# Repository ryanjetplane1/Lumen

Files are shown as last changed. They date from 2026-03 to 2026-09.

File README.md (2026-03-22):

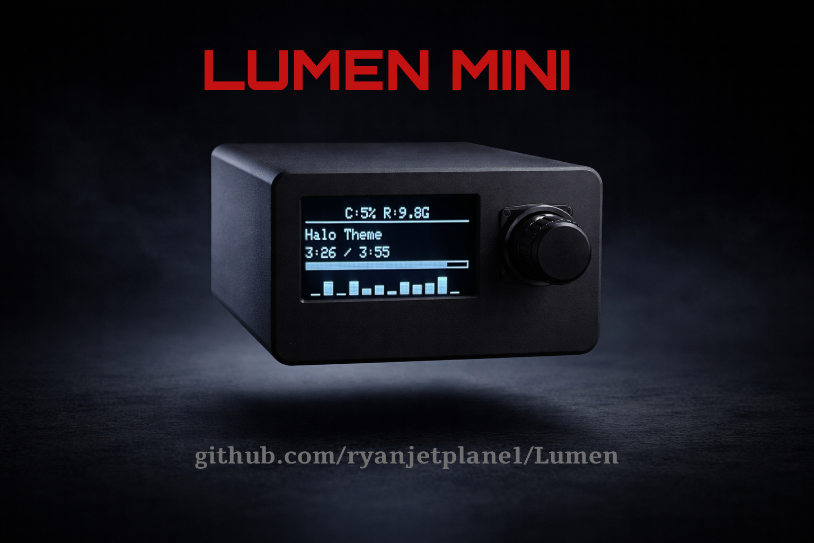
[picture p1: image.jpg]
Lumen Mini


# Lumen Mini

Lumen Mini is a pocket sized system monitor powered by USB-C that sits on your desk for extra functionality. Built on the ESP32, it houses a 1.3" OLED display showing CPU load, RAM usage, and whatever is playing. Complete with a prebuilt progress bar and a synth GUI the hardware can be reprogramed to fit your needs. When you reach for the volume, a rotary encoder handles it along with play, pause, and skip. When you turn off your PC, Lumen Mini fades to a simple clock.

---

## Features

- CPU % and RAM usage
- Current track name, progress bar, and position timer
- Synth visualizer
- Clock (12-hour)
- Volume control via rotary encoder
- Single / double / triple click for pause, next, previous track
- WiFi NTP clock fallback when PC is disconnected

---

## Hardware Required

| Part | Notes |
|---|---|
| ESP32-C3 SuperMini | Any vendor; black PCB version |
| 1.3" SH1106 OLED (128×64) | I2C, 4-pin **not** the 0.96" SSD1306 |
| Rotary encoder with pushbutton | EC11 or equivalent |
| Breadboard + jumper wires | Or solder directly |

---

## Wiring

All logic runs at **3.3V**. Do **not** use 5V — the Oled display cannot handle 5V.

### OLED Display (I2C)

| OLED Pin | ESP32-C3 SuperMini Pin |
|---|---|
| VCC | 3.3V |
| GND | GND |
| SDA | GPIO8 |
| SCL | GPIO9 |

### Rotary Encoder

| Encoder Pin | ESP32-C3 SuperMini Pin | Notes |
|---|---|---|
| VCC (+) | 3.3V | |
| GND | GND | |
| CLK (A) | **GPIO10** | Hardware interrupt pin |
| DT (B) | **GPIO2** | Hardware interrupt pin |
| SW (button) | **GPIO3** | |

---

## Software Setup

### PC Side (Python)

**Requirements:** Windows 10/11, Python 3.10+

Install dependencies:
```
pip install psutil pyserial keyboard pycaw comtypes winrt-runtime
```

Edit `gui.py` and set your COM port to whichever yours is set to:
```python
COM_PORT = 'COM3'
```

Run:
```
python gui.py
```

> The script must be running for the display to show PC stats. It will also control media keys via the encoder.

### ESP32 Side (Arduino)

**Arduino IDE board setup:**
1. In Arduino IDE, go to **File → Preferences**
2. Add to Additional Boards Manager URLs:
   `https://raw.githubusercontent.com/espressif/arduino-esp32/gh-pages/package_esp32_index.json`
3. Go to **Tools → Board → Boards Manager**, search `esp32` by Espressif and install
4. Select board: **Tools → Board → esp32 → ESP32C3 Dev Module**
5. Set **USB CDC On Boot: Enabled** (required for Serial over USB-C)

**Install libraries** via Library Manager:
- `Adafruit SH110X`
- `Adafruit GFX Library`

Edit the sketch and set your WiFi credentials:
```cpp
const char* ssid     = "your-network";
const char* password = "your-password";
```

Set your timezone offset in seconds from UTC:
```cpp
const long gmtOffset_sec = -18000;  // UTC-5 (Eastern Standard Time)
const int  daylightOffset_sec = 3600;  // 1 hour DST
```

Upload the sketch via USB-C.

---

## How It Works

```
[Windows PC]
  Python script reads:
    - CPU / RAM via psutil
    - Media info via Windows Media Transport Controls (winrt)
    - System volume via pycaw
  Sends packets over USB serial ~20x per second

[ESP32-C3 SuperMini]
  Receives packet, parses fields
  Encoder interrupts → sends CW / CCW / PAUSE / NEXT / PREV back to PC
  Python receives those and fires media/volume keyboard shortcuts
  Display renders based on current state
```

---

## Display Modes

| Condition | Display Shows |
|---|---|
| No PC connection | WiFi NTP clock + date |
| PC connected, music playing | Song name, progress bar, synth visualizer |
| PC connected, music paused | clock (12h) + Stats |
| Volume changed | Volume % overlay + bar for 1.5s |

---

## Troubleshooting

**Display shows nothing after upload**
Confirm SDA/SCL are on GPIO8/GPIO9. Confirm the display is SH1106 and not SSD1306 (different driver).

**Serial not connecting / wrong COM port**
Check Device Manager on Windows. Make sure no other program (Arduino IDE Serial Monitor, etc.) has the port open.

**Encoder feels jittery or skips**
Add a 100nF ceramic capacitor between CLK and GND, and between DT and GND, right at the encoder pins. This filters electrical noise on the interrupt lines.

**WiFi clock shows wrong time**
Adjust `gmtOffset_sec` for your timezone. EST = -18000, CST = -21600, MST = -25200, PST = -28800. If DST is active add 3600.

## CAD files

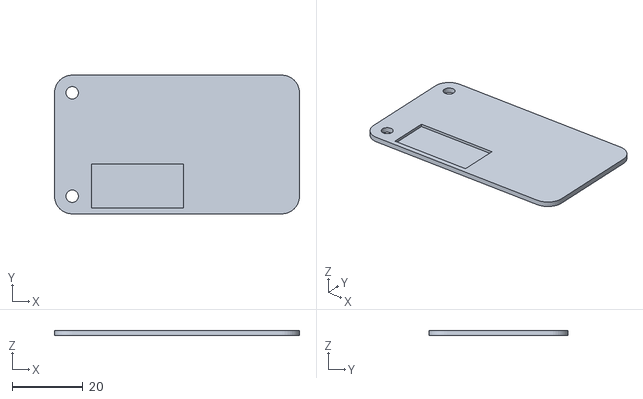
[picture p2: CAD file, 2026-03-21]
3dfiles/v4back.stl
69.2 x 39.2 x 1.50

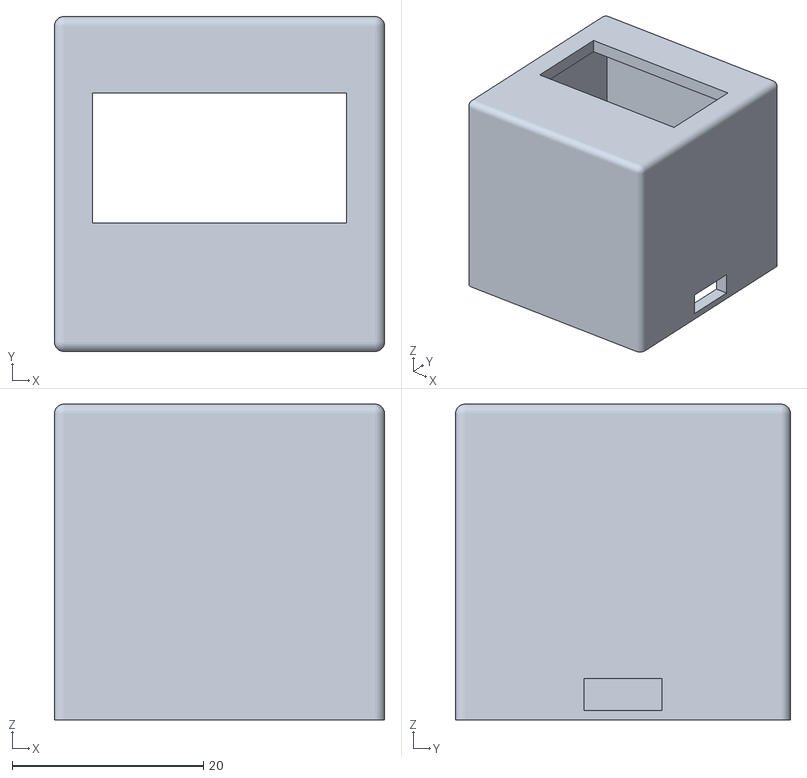
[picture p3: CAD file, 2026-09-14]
3dfiles0.96/Body5.stl
34.5 x 35.0 x 33.0

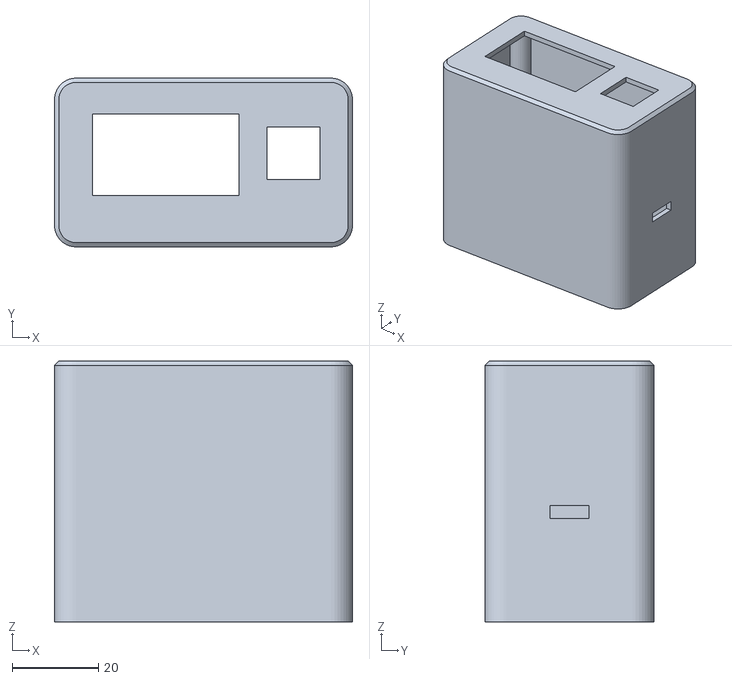
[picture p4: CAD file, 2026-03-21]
3dfiles/v5case.stl
69.2 x 39.2 x 60.6

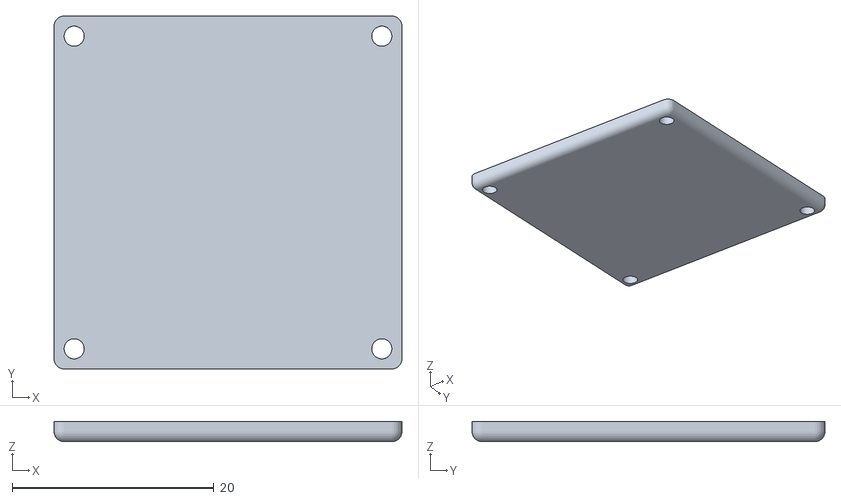
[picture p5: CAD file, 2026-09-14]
3dfiles0.96/Body6.stl
34.5 x 35.0 x 2.00

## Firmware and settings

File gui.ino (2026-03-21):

#include <WiFi.h>
#include <time.h>
#include <Wire.h>
#include <Adafruit_GFX.h>
#include <Adafruit_SH110X.h>

const char* ssid     = "timberlawn-kids";
const char* password = "11005Sugarbush";
const char* ntpServer = "pool.ntp.org";
const long  gmtOffset_sec = -18000;
const int   daylightOffset_sec = 3600;

#define SCREEN_WIDTH 128
#define SCREEN_HEIGHT 64
#define OLED_RESET -1
#define SCREEN_ADDRESS 0x3C
#define SDA_PIN 8
#define SCL_PIN 9

Adafruit_SH1106G display = Adafruit_SH1106G(SCREEN_WIDTH, SCREEN_HEIGHT, &Wire, OLED_RESET);

const int pinCLK = 10;
const int pinDT  = 2;
const int pinSW  = 3;

volatile int volumeChange = 0;
int pcVolume = 0;
unsigned long lastTickMillis   = 0;
unsigned long volDisplayTimeout = 0;
int currentPos = 0, totalDur = 0;
bool isPlaying = false, pcConnected = false;
String currentSong = "", lastSong = "";
String currentCPU = "0", currentRAM = "0", currentH = "12", currentM = "00";
int visualizerBars[12] = {0};

// ── BUTTON CLICK STATE ───────────────────────────────────────
int  clickCount       = 0;
bool btnWasPressed    = false;
unsigned long lastClickTime = 0;
const unsigned long clickTimeout = 350;  // ms window to collect clicks
const unsigned long debounce     = 40;   // ms debounce
unsigned long lastDebounceTime   = 0;
bool lastRawBtn = false;
bool stableBtn  = false;

// ── SCROLL STATE ─────────────────────────────────────────────
int  scrollOffset    = 0;
unsigned long lastScrollTime  = 0;
const int SCROLL_SPEED_MS     = 350;
const int SCROLL_PAUSE_MS     = 2000;
const int MAX_VISIBLE_CHARS   = 21;
bool scrollPausing            = false;
unsigned long scrollPauseStart = 0;
String lastScrollSong         = "";

unsigned long lastDisplayUpdate = 0;
const int DISPLAY_UPDATE_MS     = 50;

void IRAM_ATTR readEncoder() {
  static int lastCLK = -1;
  int currentCLK = digitalRead(pinCLK);
  if (currentCLK != lastCLK && currentCLK == LOW) {
    if (digitalRead(pinDT) == currentCLK) volumeChange++;
    else                                   volumeChange--;
  }
  lastCLK = currentCLK;
}

String formatTime(int totalSeconds) {
  int m = totalSeconds / 60, s = totalSeconds % 60;
  return String(m) + ":" + (s < 10 ? "0" : "") + String(s);
}

void drawCenteredText(String text, int y, int size) {
  display.setTextSize(size);
  int16_t x1, y1; uint16_t w, h;
  display.getTextBounds(text, 0, 0, &x1, &y1, &w, &h);
  display.setCursor((SCREEN_WIDTH - w) / 2, y);
  display.print(text);
}

String getValue(String data, char sep, int index) {
  int found = 0, strIndex[] = {0, -1}, maxIndex = data.length() - 1;
  for (int i = 0; i <= maxIndex && found <= index; i++) {
    if (data.charAt(i) == sep || i == maxIndex) {
      found++;
      strIndex[0] = strIndex[1] + 1;
      strIndex[1] = (i == maxIndex) ? i + 1 : i;
    }
  }
  return found > index ? data.substring(strIndex[0], strIndex[1]) : "";
}

bool barsAllZero() {
  for (int i = 0; i < 12; i++) if (visualizerBars[i] > 0) return false;
  return true;
}

void drawScrollingSong(String song, int y) {
  display.setTextSize(1);
  if (song != lastScrollSong) {
    scrollOffset     = 0;
    scrollPausing    = true;
    scrollPauseStart = millis();
    lastScrollSong   = song;
  }
  int songLen = song.length();
  if (songLen <= MAX_VISIBLE_CHARS) {
    display.setCursor(0, y);
    display.print(song);
    return;
  }
  if (scrollPausing) {
    if (millis() - scrollPauseStart >= SCROLL_PAUSE_MS) {
      scrollPausing  = false;
      lastScrollTime = millis();
    }
    display.setCursor(0, y);
    display.print(song.substring(0, MAX_VISIBLE_CHARS));
    return;
  }
  if (millis() - lastScrollTime >= SCROLL_SPEED_MS) {
    scrollOffset++;
    lastScrollTime = millis();
    if (scrollOffset >= songLen + 3) {
      scrollOffset     = 0;
      scrollPausing    = true;
      scrollPauseStart = millis();
    }
  }
  String padded = song + "   " + song;
  display.setCursor(0, y);
  display.print(padded.substring(scrollOffset, scrollOffset + MAX_VISIBLE_CHARS));
}

// ── BUTTON: debounce + multi-click detection ─────────────────
void handleButton() {
  bool rawBtn = (digitalRead(pinSW) == LOW);

  // Debounce
  if (rawBtn != lastRawBtn) lastDebounceTime = millis();
  lastRawBtn = rawBtn;
  if (millis() - lastDebounceTime < debounce) return;

  bool pressed = rawBtn;

  // Rising edge — count click
  if (pressed && !stableBtn) {
    clickCount++;
    lastClickTime = millis();
  }
  stableBtn = pressed;

  // Once the click window expires, fire the action
  if (clickCount > 0 && !pressed && (millis() - lastClickTime > clickTimeout)) {
    if      (clickCount == 1) Serial.println("PAUSE");
    else if (clickCount == 2) Serial.println("NEXT");
    else if (clickCount == 3) Serial.println("PREV");
    clickCount = 0;
  }
}

void setup() {
  Serial.begin(115200);
  Wire.begin(SDA_PIN, SCL_PIN);
  pinMode(pinCLK, INPUT_PULLUP);
  pinMode(pinDT,  INPUT_PULLUP);
  pinMode(pinSW,  INPUT_PULLUP);
  attachInterrupt(digitalPinToInterrupt(pinCLK), readEncoder, CHANGE);
  if (!display.begin(SCREEN_ADDRESS, true)) { for (;;); }
  display.clearDisplay();
  display.setTextColor(SH110X_WHITE);
  drawCenteredText("Connecting WiFi...", 25, 1);
  display.display();
  WiFi.begin(ssid, password);
  while (WiFi.status() != WL_CONNECTED) { delay(500); }
  configTime(gmtOffset_sec, daylightOffset_sec, ntpServer);
}

void loop() {
  // Encoder volume
  if (volumeChange != 0) {
    volDisplayTimeout = millis();
    if (volumeChange > 0) for (int i = 0; i < abs(volumeChange); i++) Serial.println("CW");
    else                  for (int i = 0; i < abs(volumeChange); i++) Serial.println("CCW");
    volumeChange = 0;
  }

  handleButton();

  // Serial receive
  if (Serial.available() > 0) {
    String data = Serial.readStringUntil('\n');
    if (data.indexOf('|') != -1) {
      pcConnected  = true;
      currentCPU   = getValue(data, '|', 0);
      currentRAM   = getValue(data, '|', 1);
      currentSong  = getValue(data, '|', 2);
      int incomingPos = getValue(data, '|', 3).toInt();
      totalDur     = getValue(data, '|', 4).toInt();
      String barsString = getValue(data, '|', 5);
      currentH     = getValue(data, '|', 6);
      currentM     = getValue(data, '|', 7);
      isPlaying    = (getValue(data, '|', 8).toInt() == 1);
      pcVolume     = getValue(data, '|', 9).toInt();

      if (currentSong != lastSong || abs(incomingPos - currentPos) > 5) {
        currentPos = incomingPos;
        lastSong   = currentSong;
      }
      for (int i = 0; i < 12; i++)
        visualizerBars[i] = getValue(barsString, ',', i).toInt();
    }
  }

  if (isPlaying && (millis() - lastTickMillis >= 1000)) {
    lastTickMillis = millis();
    if (currentPos < totalDur) currentPos++;
  }

  if (millis() - lastDisplayUpdate < DISPLAY_UPDATE_MS) return;
  lastDisplayUpdate = millis();

  display.clearDisplay();
  display.setTextColor(SH110X_WHITE);
  struct tm timeinfo;
  bool timeValid = getLocalTime(&timeinfo);

  if (millis() - volDisplayTimeout < 1500) {
    drawCenteredText("VOLUME", 10, 1);
    drawCenteredText(String(pcVolume) + "%", 25, 3);
    display.drawRect(10, 52, 108, 8, SH110X_WHITE);
    int volBar = map(pcVolume, 0, 100, 0, 104);
    display.fillRect(12, 54, volBar, 4, SH110X_WHITE);
  }
  else if (!pcConnected) {
    if (timeValid) {
      char hStr[5], mStr[5], dStr[30];
      strftime(hStr, 5, "%I", &timeinfo);
      strftime(mStr, 5, "%M", &timeinfo);
      strftime(dStr, 30, "%b %d", &timeinfo);
      String finalH = String(hStr);
      if (finalH.startsWith("0")) finalH = finalH.substring(1);
      drawCenteredText(finalH + ":" + String(mStr), 15, 3);
      drawCenteredText(String(dStr), 50, 1);
    }
  } else {
    drawCenteredText("C:" + currentCPU + "% R:" + currentRAM, 6, 1);
    display.drawLine(0, 15, 128, 15, SH110X_WHITE);

    if (isPlaying || !barsAllZero()) {
      drawScrollingSong(currentSong, 20);
      display.setCursor(0, 32);
      display.print(formatTime(currentPos) + " / " + formatTime(totalDur));
      display.drawRect(0, 42, 128, 5, SH110X_WHITE);
      if (totalDur > 0) {
        int barWidth = map(constrain(currentPos, 0, totalDur), 0, totalDur, 0, 126);
        display.fillRect(1, 43, barWidth, 3, SH110X_WHITE);
      }
      for (int i = 0; i < 12; i++) {
        int barH = map(visualizerBars[i], 0, 32, 0, 16);
        display.fillRect(i * 10 + 4, 64 - barH, 7, barH, SH110X_WHITE);
      }
    } else {
      drawCenteredText(currentH + ":" + currentM, 30, 3);
    }
  }
  display.display();
}

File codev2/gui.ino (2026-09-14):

#include <Wire.h>
#include <Adafruit_GFX.h>
#include <Adafruit_SSD1306.h>
#include <math.h>

#define SCREEN_WIDTH 128
#define SCREEN_HEIGHT 64
#define OLED_RESET -1
#define SCREEN_ADDRESS 0x3C
#define SDA_PIN 8
#define SCL_PIN 9

Adafruit_SSD1306 display(SCREEN_WIDTH, SCREEN_HEIGHT, &Wire, OLED_RESET);

float totalDur = 0.0f;
float basePos = 0.0f;
unsigned long basePosTime = 0;
float lastIncomingPos = 0.0f;
bool haveIncomingPos = false;
bool isPlaying = false, pcConnected = false;
bool everReceivedSerial = false;
unsigned long lastPcDataTime = 0;
String currentSong = "", lastSong = "";
String currentCPU = "0", currentRAM = "0", currentH = "12", currentM = "00";
String currentArtist = "";

bool lastIsPlayingState = false;
unsigned long playStartTime = 0;
const unsigned long BARS_RAMP_MS = 1000;
int visualizerBars[12] = {0};
float displayBars[12] = {0};
unsigned long lastBarsUpdateTime = 0;
const float BAR_FALL = 1.6;
const unsigned long BARS_STALE_MS = 600;

String serialBuffer = "";

int  scrollOffset    = 0;
unsigned long lastScrollTime  = 0;
const int SCROLL_SPEED_MS     = 350;
const int SCROLL_PAUSE_MS     = 2000;
const int MAX_VISIBLE_CHARS   = 21;
bool scrollPausing            = false;
unsigned long scrollPauseStart = 0;
String lastScrollSong         = "";

unsigned long lastDisplayUpdate = 0;
const int DISPLAY_UPDATE_MS     = 50;

bool lastPcConnected      = false;
bool displayPcConnected   = false;
unsigned long pcChangeTime = 0;
const unsigned long PC_DEBOUNCE_MS = 1500;
const unsigned long PC_TIMEOUT_MS  = 2000;

String formatTime(int totalSeconds) {
  int m = totalSeconds / 60, s = totalSeconds % 60;
  return String(m) + ":" + (s < 10 ? "0" : "") + String(s);
}

void drawCenteredText(String text, int y, int size) {
  display.setTextSize(size);
  int16_t x1, y1; uint16_t w, h;
  display.getTextBounds(text, 0, 0, &x1, &y1, &w, &h);
  display.setCursor((SCREEN_WIDTH - w) / 2, y);
  display.print(text);
}

String getValue(String data, char sep, int index) {
  int found = 0, strIndex[] = {0, -1}, maxIndex = data.length() - 1;
  for (int i = 0; i <= maxIndex && found <= index; i++) {
    if (data.charAt(i) == sep || i == maxIndex) {
      found++;
      strIndex[0] = strIndex[1] + 1;
      strIndex[1] = (i == maxIndex) ? i + 1 : i;
    }
  }
  return found > index ? data.substring(strIndex[0], strIndex[1]) : "";
}

String oledText(String text) {
  String clean;
  clean.reserve(text.length());
  for (unsigned int i = 0; i < text.length(); i++) {
    char c = text.charAt(i);
    clean += (c >= 32 && c <= 126) ? c : '?';
  }
  return clean;
}

bool barsAllZero() {
  for (int i = 0; i < 12; i++) if (visualizerBars[i] > 0) return false;
  return true;
}

void processSerialLine(String data) {
  if (data.indexOf('|') == -1) return;
  unsigned long now = millis();
  pcConnected  = true;
  everReceivedSerial = true;
  lastPcDataTime = millis();
  currentCPU   = getValue(data, '|', 0);
  currentRAM   = getValue(data, '|', 1);
  String incomingSong = oledText(getValue(data, '|', 2));
  float incomingPos = getValue(data, '|', 3).toFloat();
  float incomingDur = getValue(data, '|', 4).toFloat();
  String barsString = getValue(data, '|', 5);
  currentH     = getValue(data, '|', 6);
  currentM     = getValue(data, '|', 7);
  bool incomingPlaying = (getValue(data, '|', 8).toInt() == 1);
  String incomingArtist = oledText(getValue(data, '|', 9));

  bool trackChanged = incomingSong != currentSong ||
                      incomingArtist != currentArtist ||
                      incomingDur != totalDur;
  bool playStateChanged = incomingPlaying != isPlaying;
  float localPos = basePos;
  if (isPlaying) {
    localPos += (now - basePosTime) / 1000.0f;
  }
  bool positionJumped = haveIncomingPos &&
                        fabsf(incomingPos - lastIncomingPos) > 3.0f;

  if (trackChanged || positionJumped || (playStateChanged && incomingPlaying)) {
    basePos = incomingPos;
    basePosTime = now;
  } else if (playStateChanged) {
    basePos = max(localPos, incomingPos);
    basePosTime = now;
  }
  lastIncomingPos = incomingPos;
  haveIncomingPos = true;

  currentSong  = incomingSong;
  totalDur     = incomingDur;
  isPlaying    = incomingPlaying;
  currentArtist = incomingArtist;
  lastSong     = currentSong;
  for (int i = 0; i < 12; i++)
    visualizerBars[i] = getValue(barsString, ',', i).toInt();
  lastBarsUpdateTime = millis();
}

void pollSerial() {
  while (Serial.available() > 0) {
    char c = Serial.read();
    if (c == '\n') {
      processSerialLine(serialBuffer);
      serialBuffer = "";
    } else if (c != '\r') {
      serialBuffer += c;
      if (serialBuffer.length() > 200) serialBuffer = "";
    }
  }
}

void drawScrollingSong(String song, int y) {
  display.setTextSize(1);
  if (song != lastScrollSong) {
    scrollOffset     = 0;
    scrollPausing    = true;
    scrollPauseStart = millis();
    lastScrollSong   = song;
  }
  int songLen = song.length();
  if (songLen <= MAX_VISIBLE_CHARS) {
    display.setCursor(0, y);
    display.print(song);
    return;
  }
  if (scrollPausing) {
    if (millis() - scrollPauseStart >= SCROLL_PAUSE_MS) {
      scrollPausing  = false;
      lastScrollTime = millis();
    }
    display.setCursor(0, y);
    display.print(song.substring(0, MAX_VISIBLE_CHARS));
    return;
  }
  if (millis() - lastScrollTime >= SCROLL_SPEED_MS) {
    scrollOffset++;
    lastScrollTime = millis();
    if (scrollOffset >= songLen + 3) {
      scrollOffset     = 0;
      scrollPausing    = true;
      scrollPauseStart = millis();
    }
  }
  String padded = song + "   " + song;
  display.setCursor(0, y);
  display.print(padded.substring(scrollOffset, scrollOffset + MAX_VISIBLE_CHARS));
}

void setup() {
  Serial.begin(115200);
  Wire.begin(SDA_PIN, SCL_PIN);
  if (!display.begin(SSD1306_SWITCHCAPVCC, SCREEN_ADDRESS)) { for (;;); }
  display.clearDisplay();
  display.setTextColor(SSD1306_WHITE);
  drawCenteredText("Waiting for PC...", 25, 1);
  display.display();
  serialBuffer.reserve(200);
}
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
